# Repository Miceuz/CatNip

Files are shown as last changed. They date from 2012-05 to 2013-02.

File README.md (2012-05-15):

CatNip - LPC1343 Developement board
======

This is a derivative work of microbuilderÕs LPC1343 Reference Design http://www.microbuilder.eu/projects/LPC1343ReferenceDesign/

The design is aimed at creating a platform that enables to create USB enabled devices quickly and efficiently. The board is optimised for creating devices which will be contained within a case. 

The main differences from microbuilderÕs design:
 - USB connection header is added in order to facilitate adding an external case - mounted USB connector that is placed far away from the board
 - RESET pin is in a breakout in order to allow putting a reset button on the device case.
 - power is connected via screw terminals
 - eeprom in SO8 package is used as itÕs more common
 - separate power header is added to export regulated and incomming voltages to daughter boards
 - most of 3.3V and GND connections removed from breakout as it encourages ground loops, GND connections are left near communication pins (SPI, I2C, RXTX) for easier prototyping, 3.3V connection is left near ADC inputs as itÕs handy to limit ADC input to 3.3V by adding a diode
 - All UART pins except RX and TX are reclaimed (who uses UART anyway?:)
 - More ADC pins added
 - LED pin is added to header
 - JTAG connector removed and itÕs pins reclaimed for GPIO/ADC

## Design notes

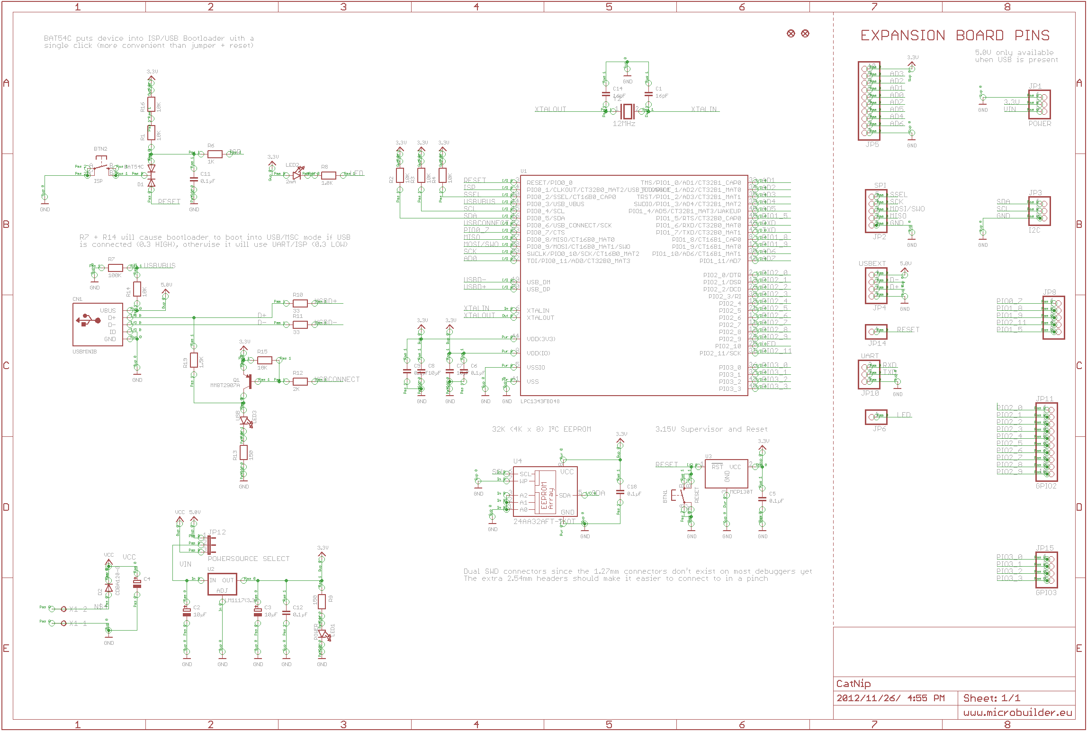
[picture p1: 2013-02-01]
schematics.png

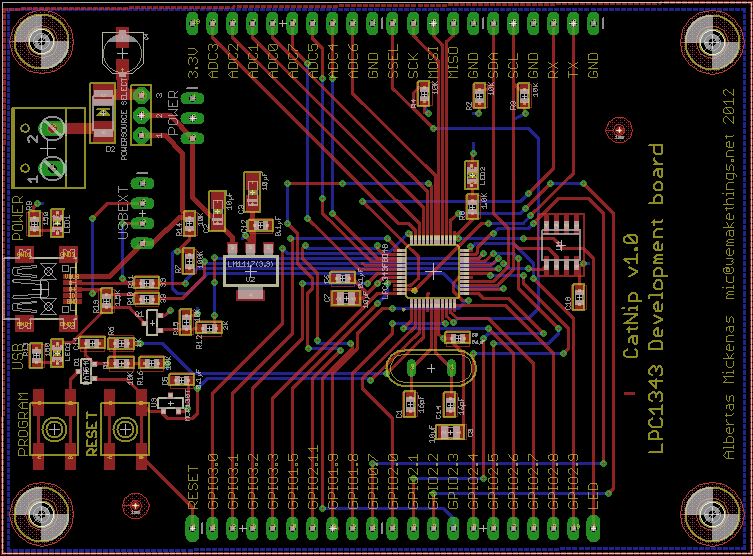
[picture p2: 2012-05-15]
pcb.png

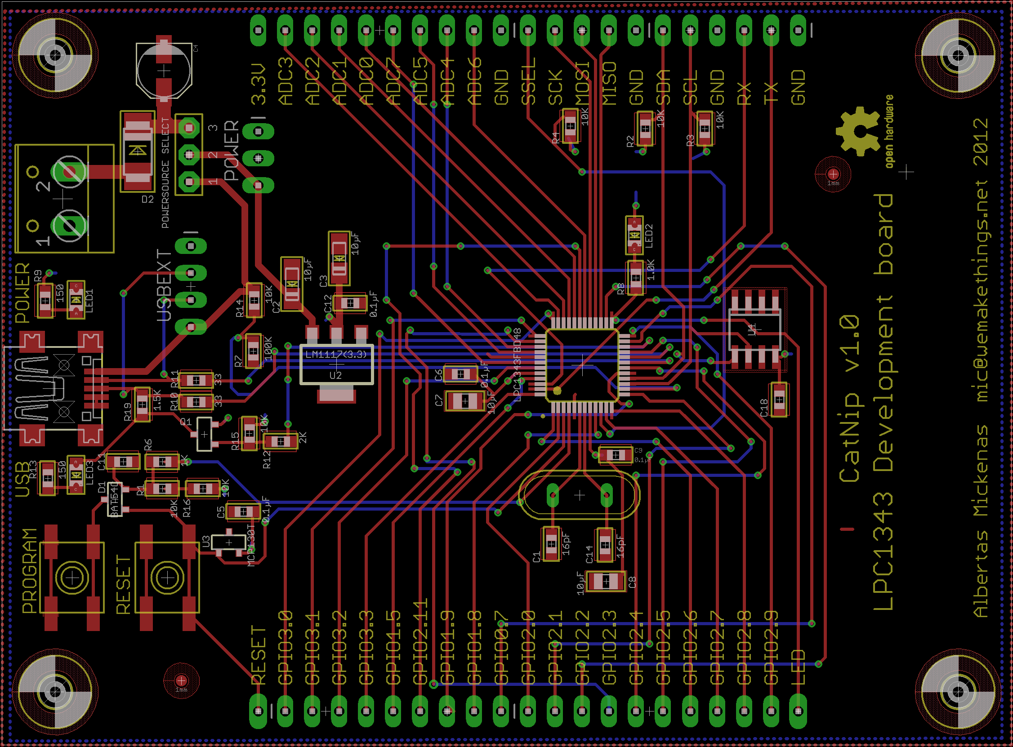
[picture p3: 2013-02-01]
board.png

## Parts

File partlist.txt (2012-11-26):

Partlist

Exported from CatNip.sch at 2012/10/24/ 10:50 AM

EAGLE Version 5.11.0 Copyright (c) 1988-2010 CadSoft

Part     Value              Device                      Package        Library      Sheet

BTN1     RESET              BUTTON_SMT                  EVQ-Q2         microbuilder 1
BTN2     ISP                BUTTON_SMT                  EVQ-Q2         microbuilder 1
* C1       16pF               CAP_CERAMIC0603             0603           microbuilder 1
* C2       10µF               CAP_TANTALUMA/3216_REFLOW   EIA3216-18/A-R microbuilder 1
* C3       10µF               CAP_TANTALUMA/3216_REFLOW   EIA3216-18/A-R microbuilder 1
* C4                          CAP_ELECTROLYTICPANASONIC_C PANASONIC_C    microbuilder 1
* C5       0.1µF              CAP_CERAMIC0603             0603           microbuilder 1
* C6       0.1µF              CAP_CERAMIC0603             0603           microbuilder 1
* C7       10µF               CAP_CERAMIC0805             0805           microbuilder 1
* C8       10µF               CAP_CERAMIC0805             0805           microbuilder 1
* C9       0.1µF              CAP_CERAMIC0603             0603           microbuilder 1
* C11      0.1µF              CAP_CERAMIC0603             0603           microbuilder 1
* C12      0.1µF              CAP_CERAMIC0603             0603           microbuilder 1
* C14      16pF               CAP_CERAMIC0603             0603           microbuilder 1
* C18      0.1µF              CAP_CERAMIC0603             0603           microbuilder 1
CN1      USBMINIB           USBMINIB                    USB-MINIB      microbuilder 1
* D1       BAT54C             BAT54C                      SOT23-R        microbuilder 1
D2       CDBA120-G          DIODESMA                    SMADIODE       microbuilder 1
JP1      POWER              HEADER-1X3                  1X03_OVAL      microbuilder 1
JP2      SPI                HEADER-1X5                  1X05_OVAL      microbuilder 1
JP3      I2C                HEADER-1X3                  1X03_OVAL      microbuilder 1
JP4      USBEXT             HEADER-1X4                  1X04_OVAL      microbuilder 1
JP5                         HEADER-1X10                 1X10_OVAL      microbuilder 1
JP6                         HEADER-1X1                  1X01_OVAL      microbuilder 1
JP8                         HEADER-1X5                  1X05_OVAL      microbuilder 1
JP10     UART               HEADER-1X3                  1X03_OVAL      microbuilder 1
JP11     GPIO2              HEADER-1X10                 1X10_OVAL      microbuilder 1
JP12     POWERSOURCE SELECT JUMPER3                     JUMPER3        microbuilder 1
JP14                        HEADER-1X1                  1X01_OVAL      microbuilder 1
JP15     GPIO3              HEADER-1X4                  1X04_OVAL      microbuilder 1
* LED1     POWER              LED0805                     CHIPLED_0805   microbuilder 1
* LED2     2mA                LED0805                     CHIPLED_0805   microbuilder 1
* LED3     USB                LED0805                     CHIPLED_0805   microbuilder 1
* Q1       MMBT2907A          TRANSISTOR_PNPSOT23-REFLOW  SOT23-R        microbuilder 1
* R1       10K                RESISTOR0603                0603           microbuilder 1
* R2       10K                RESISTOR0603                0603           microbuilder 1
* R3       10K                RESISTOR0603                0603           microbuilder 1
* R4       10K                RESISTOR0603                0603           microbuilder 1
* R6       1K                 RESISTOR0603                0603           microbuilder 1
R7       100K               RESISTOR0603                0603           microbuilder 1
* R8       1.0K               RESISTOR0603                0603           microbuilder 1
* R9       150                RESISTOR0603                0603           microbuilder 1
* R10      33                 RESISTOR0603                0603           microbuilder 1
* R11      33                 RESISTOR0603                0603           microbuilder 1
* R12      2K                 RESISTOR0603                0603           microbuilder 1
* R13      150                RESISTOR0603                0603           microbuilder 1
* R14      10K                RESISTOR0603                0603           microbuilder 1
* R15      10K                RESISTOR0603                0603           microbuilder 1
* R16      10K                RESISTOR0603                0603           microbuilder 1
* R19      1.5K               RESISTOR0603                0603           microbuilder 1
* U1       LPC1343FBD48       LPC1343_QFP                 LQFP48         microbuilder 1
* U2       LM1117(3.3)        LM1117SOT223-REFLOW         SOT223-R       microbuilder 1
* U3       MCP130T            MCP130TREFLOW               SOT23-R        microbuilder 1
* U4       24AA32AFT-I/OT     24C32ASN                    SO-08          microchip    1
X1                          W237-02P                    W237-132       con-wago-508 1
Y2       12MHz              XTAL/S                      QS             special      1

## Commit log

2012-05-15 Initial import
    [CatNip.brd, CatNip.sch]
2012-05-15 oshw logo added
    [CatNip.brd]
2012-05-15 + pcb pic
2012-11-26 kitteh - an expansion board to CatNip
    [kitteh.brd, kitteh.sch]
2013-02-01 + pics of schematics and board for eagle free people
